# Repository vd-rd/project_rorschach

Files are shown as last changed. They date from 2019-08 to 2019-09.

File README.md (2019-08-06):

## E-Ink Driving board

E-Ink screens have a lot of advantages compared to traditional TFT displays. They can hold the image painted without power applied, making them usefull for low power/embedded applications. Moreover, from eastern suppliers they can be aquired for modest prices (comparing with the price of a LCD with the same diagonal). However, documentation is scarce and they require additional control and power requirements. This project addresses this shortcomings providing an open, modular hardware platform for driving various e-ink displays from a simple uController.

More information about suported screens and features can be found [here](docs/MATRIX.md).

### Technical features:
  - provides voltages for displays upto 10inch (VEE, VNEG, VCOM, VCC, VPOS, VDDH)
  - generates control signals for syncing data to screen
  - reads waveform from screen eeprom
  - leverages displaying data on the screen using the embedded FPGA

### Resources used:
  - http://essentialscrap.com/eink/
  - http://spritesmods.com/?art=einkdisplay
  - https://hackaday.io/project/21168-fpga-eink-controller
  - https://wenku.baidu.com/view/00bbfb6727d3240c8447efd5.html?pn=NaN
  - https://github.com/plasticlogic/libplhw/
  - http://www.gocompanion.co/index.php
  - https://github.com/dqydj/PaperBack_EPaper_Display
  - https://hackaday.io/project/11537-nekocal-an-e-ink-calendar

Essential parts:
  - iCE40HX1
  - TPS65185

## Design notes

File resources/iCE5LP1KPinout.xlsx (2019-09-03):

# Pin Out For iCE40 Ultra 1K
# Revision 0.6, Fixed Differential Pair Column
# Updated May 1, 2015
FNC | Pin Type | BANK | Differential Pair | WLCS36 | CM36A | SG48
IOB_0a | DPIO | 2 | TRUE_of_IOB_1b | - | D6 | 46
IOB_1b | DPIO | 2 | TRUE_of_IOB_0a | - | D1 | -
IOB_2a | DPIO | 2 | TRUE_of_IOB_3b | F6 | C1 | 47
IOB_3b_G6 | DPIO / GBIN | 2 | COMP_of_IOB_2a | E6 | D2 | 44
IOB_4a | DPIO | 2 | TRUE_of_IOB_5b | D6 | F1 | 48
IOB_5b | DPIO | 2 | COMP_of_IOB_4a | D5 | E1 | 45
IOB_6a | DPIO | 2 | TRUE_of_IOB_7b | F5 | F3 | 2
IOB_7b | DPIO | 2 | COMP_of_IOB_6a | E5 | E2 | -
IOB_8a | PIO | 2 | TRUE_of_IOB_9b | - | F2 | 4
IOB_9b | PIO | 2 | COMP_of_IOB_8a | - | - | 3
IOB_10a | DPIO | 1 | TRUE_of_IOB_11b | B4 | - | -
IOB_11b_G5 | PIO / GBIN | 1 | COMP_of_IOB_10a | F4 | - | -
creset_b | CONFIG | 1 |  | D3 | F4 | 8
IOB_13b | PIO | 1 |  | - | - | 6
CDONE | CONFIG | 1 |  | - | - | 7
IOB_16a | PIO | 1 |  | F3 | - | 9
IOB_18a | PIO | 1 |  | - | - | 10
IOB_20a | PIO | 1 |  | E3 | - | 11
IOB_22a | PIO | 1 | TRUE_of_IOB_23b | - | - | 12
IOB_23b | PIO | 1 | COMP_of_IOB_22a | - | - | 21
IOB_24a | PIO | 1 |  | - | - | 13
IOB_25b_G3 | PIO / GBIN | 1 |  | C2 | - | 20
IOB_26a | DPIO | 1 | TRUE_of_IOB_27b | B1 | - | -
IOB_27b | DPIO | 1 | COMP_of_IOB_26a | D2 | - | -
IOB_29b | PIO | 1 |  | E2 | - | 19
IOB_30a | DPIO | 1 | TRUE_of_IOB_31b | C1 | - | -
IOB_31b | DPIO | 1 | COMP_of_IOB_30a | B2 | - | 18
IOB_32a_SPI_SO | PIO / CONFIG_SPI | 1 |  | F2 | F6 | 14
IOB_33b_SPI_SI | PIO / CONFIG_SPI | 1 |  | D1 | E5 | 17
IOB_34a_SPI_SCK | PIO / CONFIG_SPI | 1 |  | E1 | E6 | 15
IOB_35b_SPI_CSN | PIO / CONFIG_SPI | 1 |  | F1 | F5 | 16
IOT_36b | PIO | 0 | COMP_of_IOT_37a | - | B2 | 25
IOT_37a | PIO | 0 | TRUE_of_IOT_36b | - | C2 | 23
IOT_38b | PIO | 0 | COMP_of_IOT_39a | - | A3 | 27
IOT_39a | PIO | 0 | TRUE_of_IOT_38b | - | - | 26
IOT_41a | PIO | 0 |  | - | - | 28
IOT_42b | PIO | 0 | COMP_of_IOT_43a | - | A4 | 31
IOT_43a | PIO | 0 | TRUE_of_IOT_42b | - | - | 32
IOT_44b | PIO | 0 | COMP_of_IOT_45a | - | - | 34
IOT_45a_G1 | PIO / GBIN | 0 | TRUE_of_IOT_44b | - | C6 | 37
IOT_46b_G0 | PIO / GBIN | 0 |  | B5 | B6 | 35
IOT_48b | PIO | 0 | COMP_of_IOT_49a | - | A5 | 36
IOT_49a | PIO | 0 | TRUE_of_IOT_48b | - | - | 43
IOT_50b | PIO | 0 | COMP_of_IOT_51a | - | B5 | 38
IOT_51a | PIO | 0 | TRUE_of_IOT_50b | - | - | 42
RGB2 | LED | 0 |  | A6 | A1 | 39
RGB1 | LED | 0 |  | B6 | B1 | 40
RGB0 | LED | 0 |  | C6 | A2 | 41
GND | GND | GND |  | A3 | C3 | -
GND | GND | GND |  | C5 | C4 | -
VCC | VCC | VCC |  | A5 | D3 | 5
VCC | VCC | VCC |  | - | - | 30
VCCIO_0 | VCCIO | 0 |  | A4 | B3 | 33
VCCIO_2 | VCCIO | 2 |  | C4 | E3 | 1
SPI_Vccio1 | VCCIO | 1 |  | C3 | E4 | 22
VCCPLL | VCCPLL | VCCPLL |  | B3 | D4 | 29
VPP_2V5 | VPP | VPP |  | D4 | B4 | 24
IOB_9b_CDONE | PIO / CONFIG | 2 |  | - | D5 | -
IOB_12A_G4_CDONE | PIO / GBIN / CONFIG | 1 |  | E4 | - | -
IRLED | IRLED | 0 |  | A2 | A6 | -
GND_led | GND_LED | GND_LED |  | A1 | C5 | -

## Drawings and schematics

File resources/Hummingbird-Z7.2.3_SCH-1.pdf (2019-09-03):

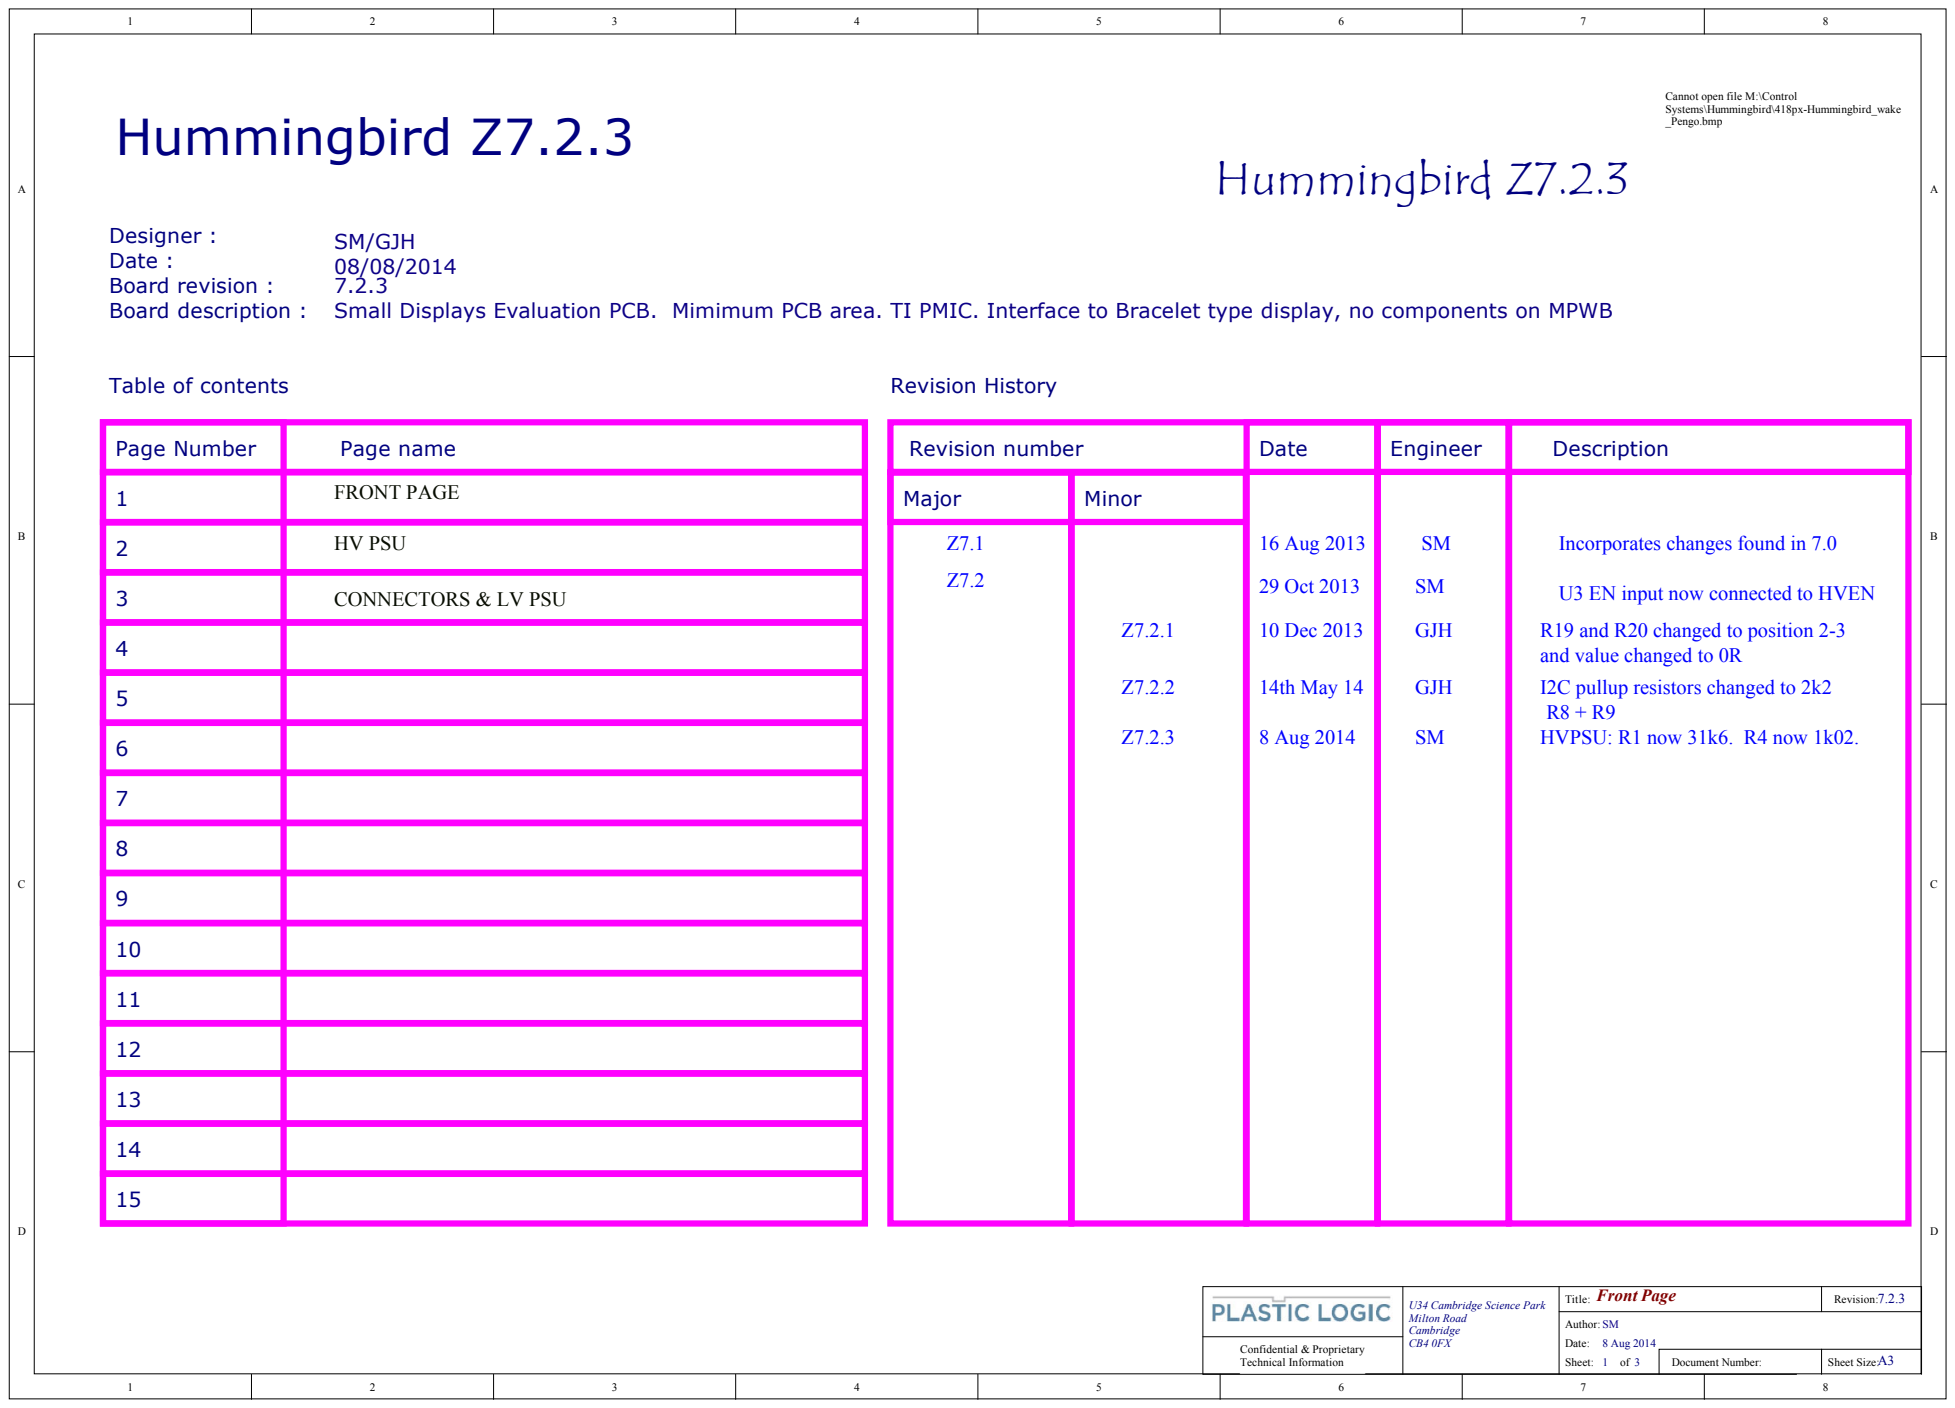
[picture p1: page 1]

Cannot open file M:\Control
Systems\Hummingbird\418px-Hummingbird_wake
_Pengo.bmp

SM/GJH
Small Displays Evaluation PCB. Mimimum PCB area. TI PMIC. Interface to Bracelet type display, no components on MPWB

2 | HV PSU

3 | CONNECTORS & LV PSU

and value changed to 0R

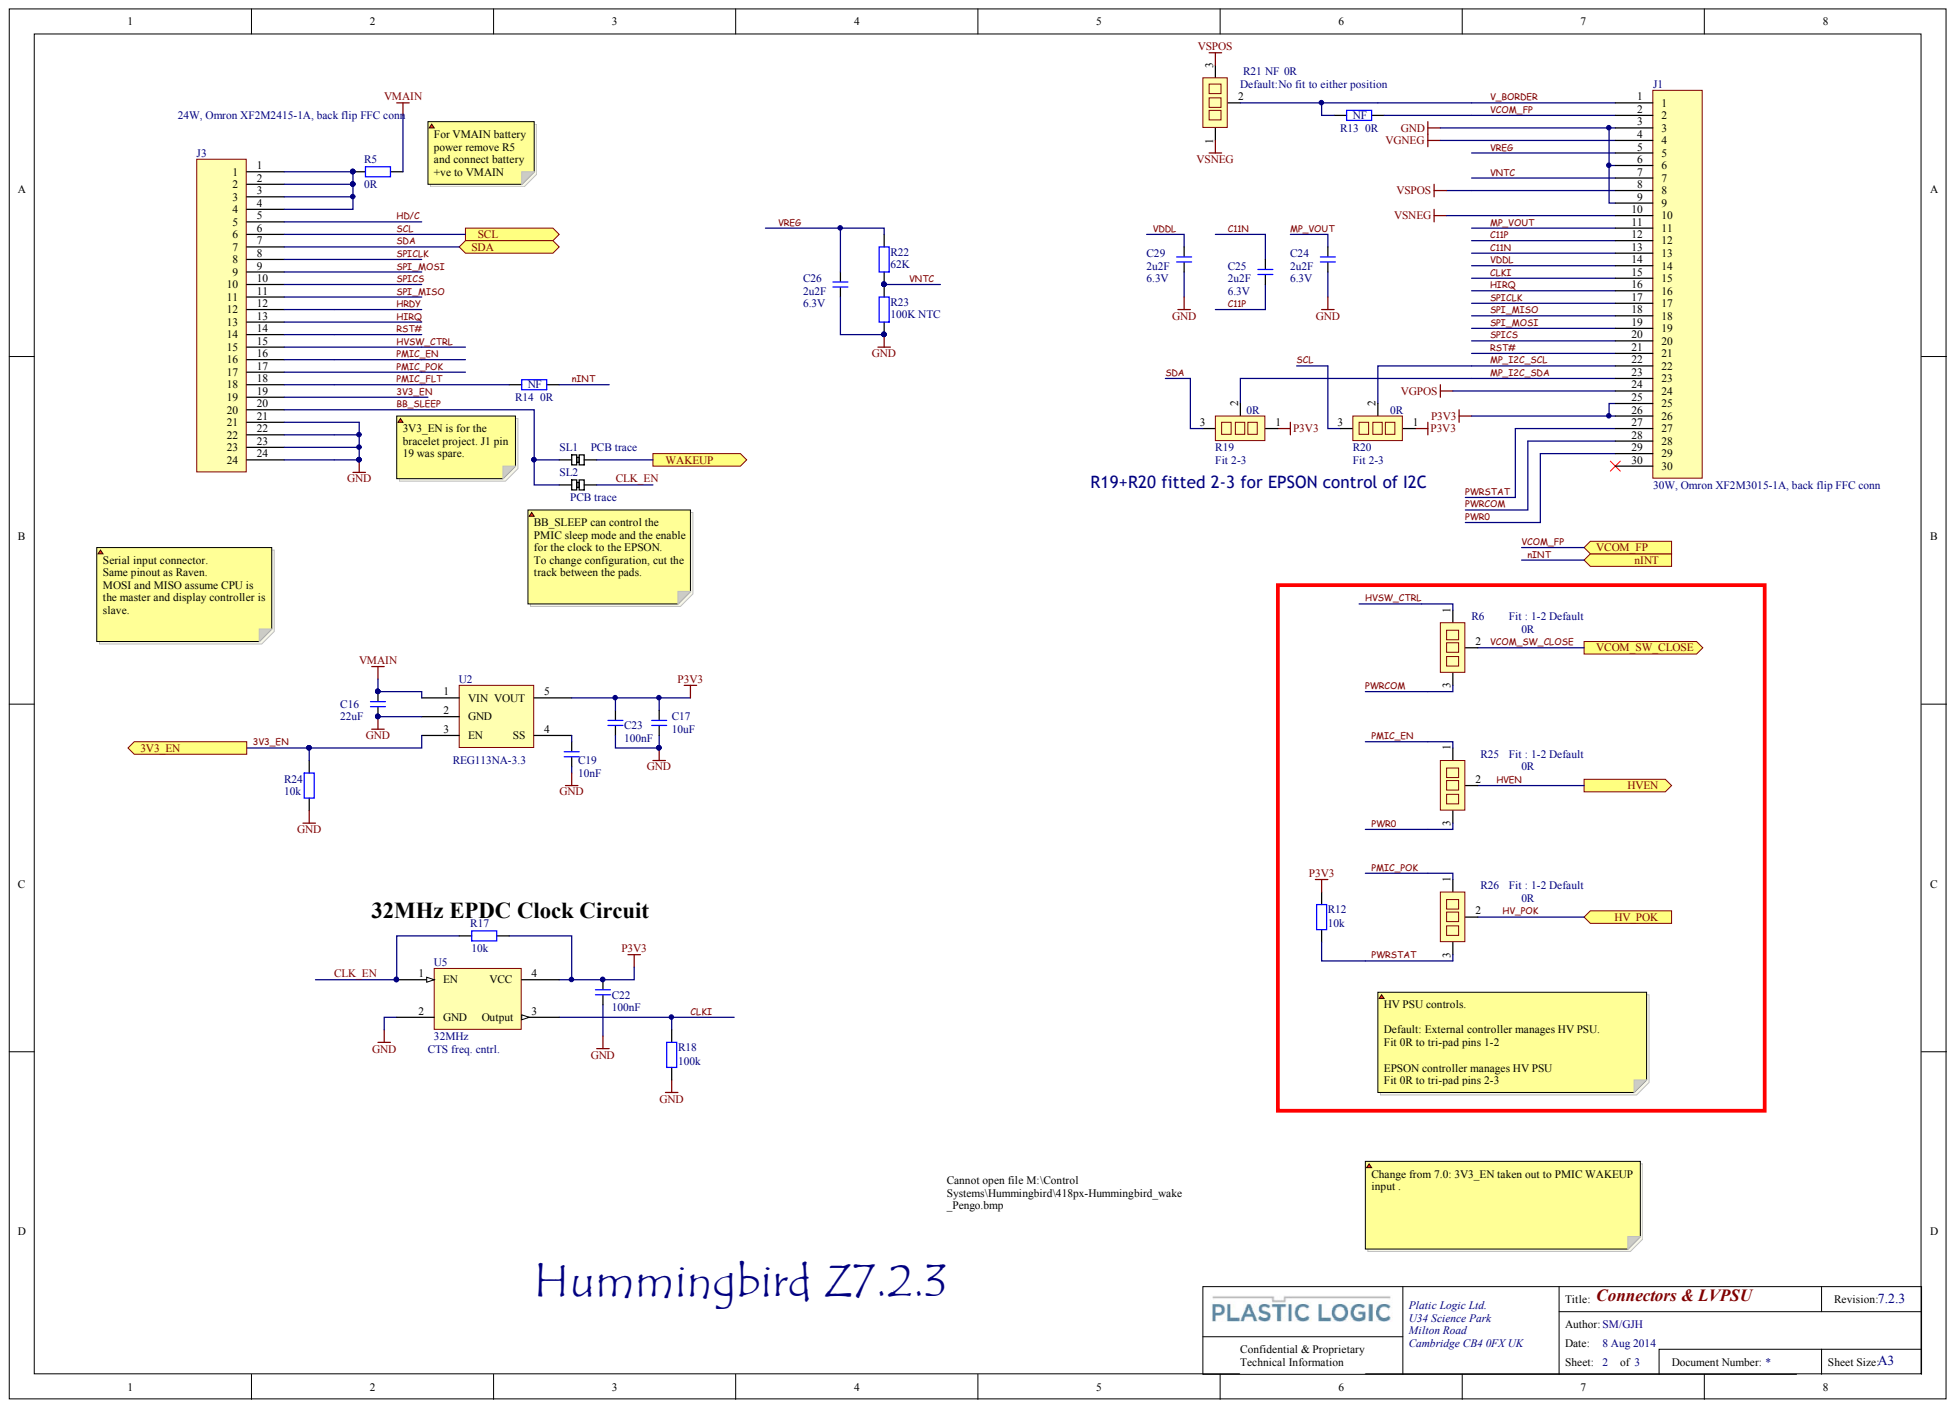
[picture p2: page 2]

Default:No fit to either position

24W, Omron XF2M2415-1A, back flip FFC conn

VREG | 5 5

R19+R20 fitted 2-3 for EPSON control of I2C

30W, Omron XF2M3015-1A, back flip FFC conn

BB_SLEEP can control the
PMIC sleep mode and the enable
for the clock to the EPSON.
To change configuration, cut the
track between the pads.

Serial input connector.
Same pinout as Raven.
MOSI and MISO assume CPU is
the master and display controller is
slave.

Default: External controller manages HV PSU.
Fit 0R to tri-pad pins 1-2

EPSON controller manages HV PSU
Fit 0R to tri-pad pins 2-3

Cannot open file M:\Control
Systems\Hummingbird\418px-Hummingbird_wake
_Pengo.bmp

Change from 7.0: 3V3_EN taken out to PMIC WAKEUP
input .

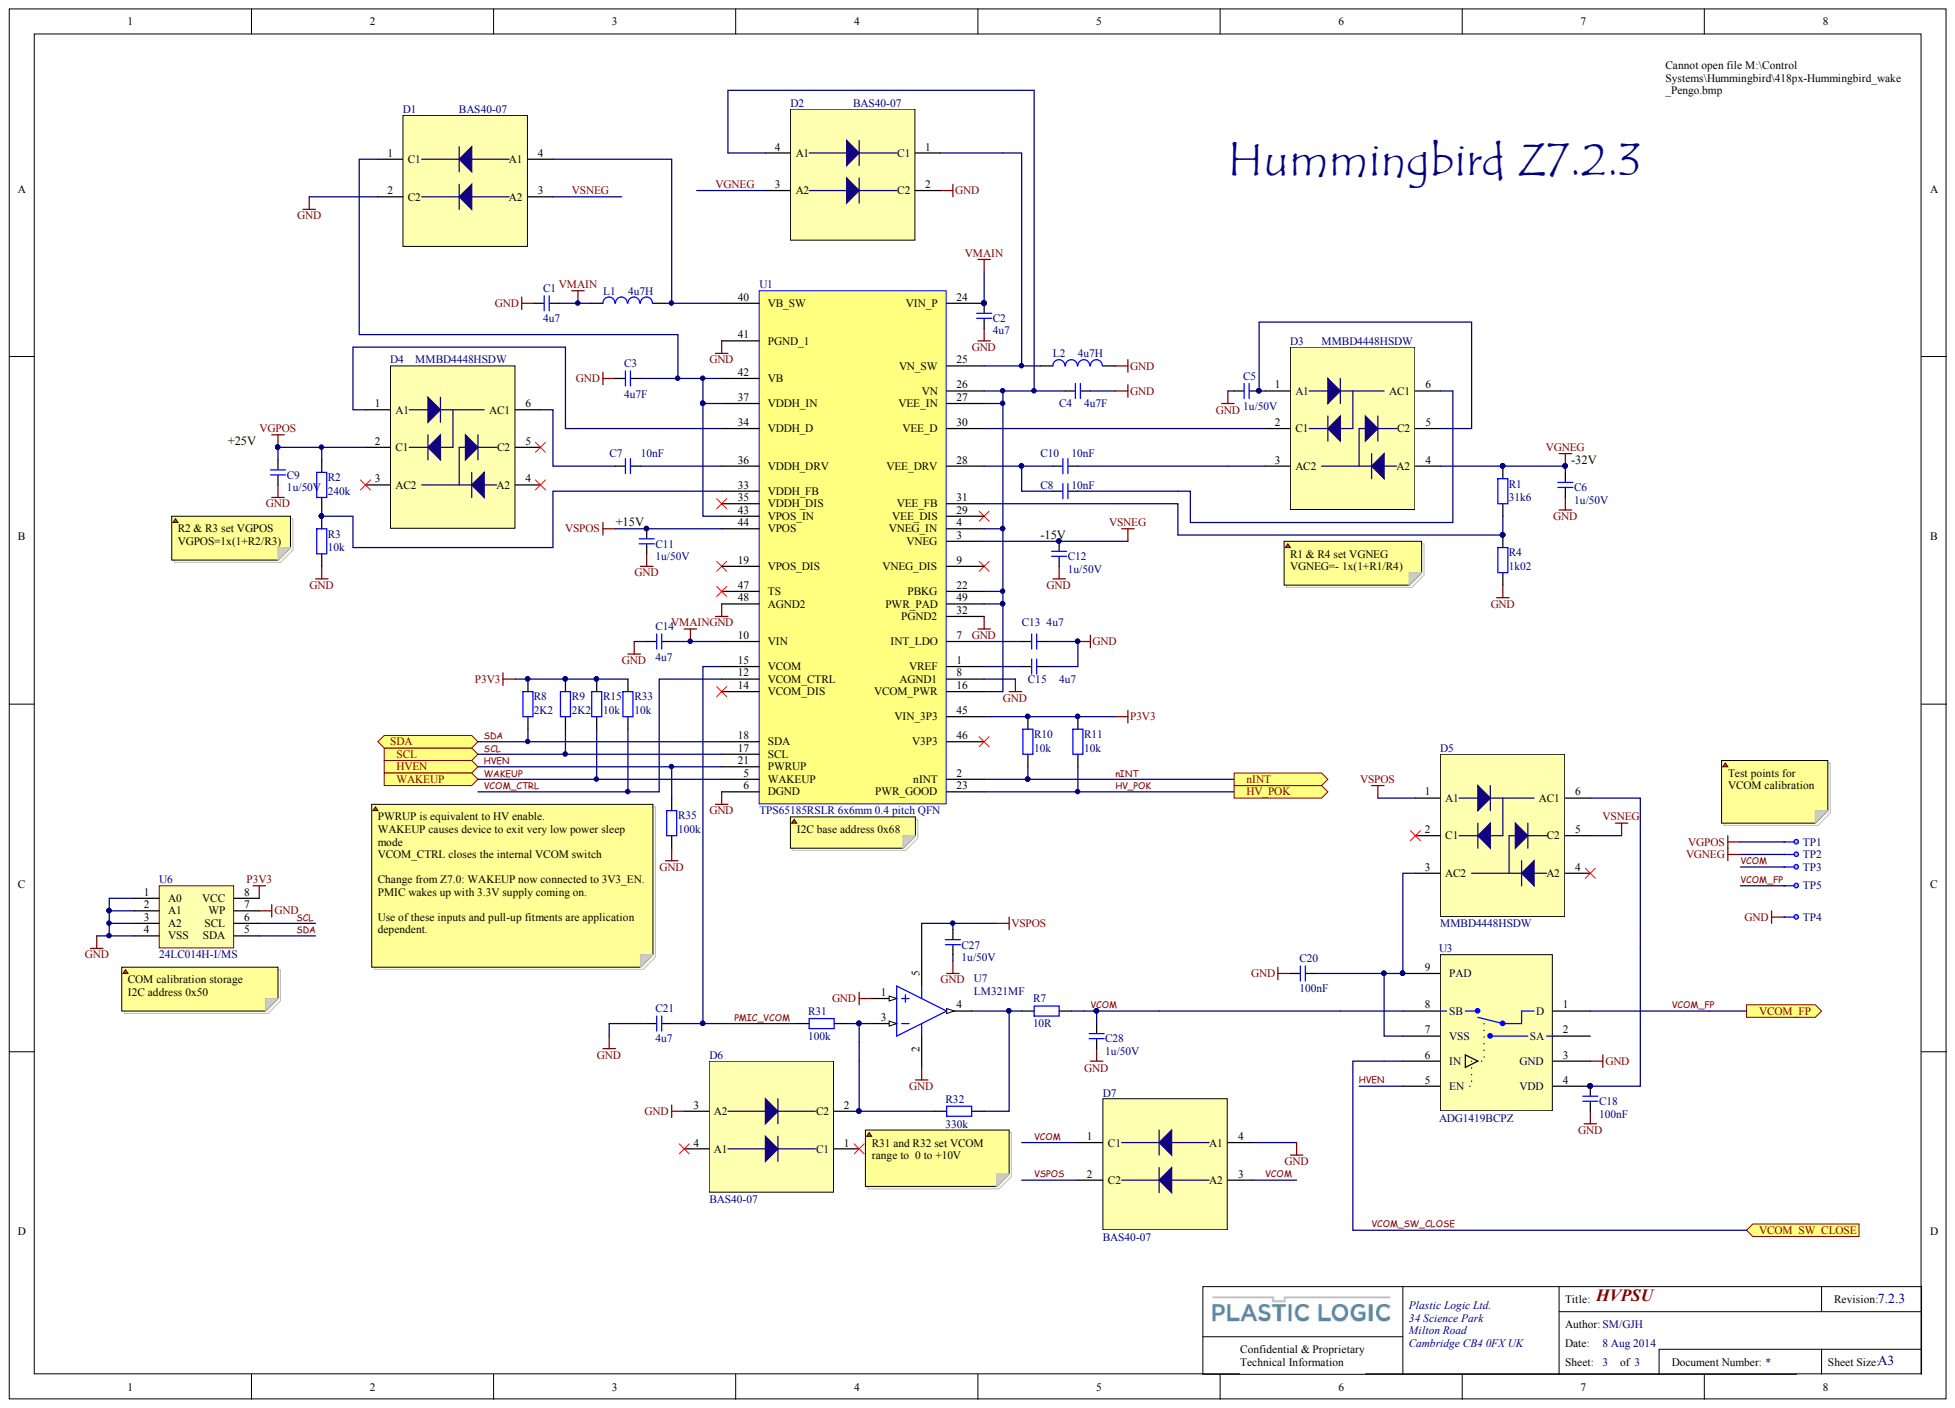
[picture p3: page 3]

Cannot open file M:\Control
Systems\Hummingbird\418px-Hummingbird_wake
_Pengo.bmp

VSNEG

VMAIN

VCOM_DIS 14

SCL | | | SCL 17
HVEN | | | PWRUP 21

VCOM_CTRL | DGND 6 | | HV_POK

WAKEUP 5

PWRUP is equivalent to HV enable.
WAKEUP causes device to exit very low power sleep
mode
VCOM_CTRL closes the internal VCOM switch

C1 2 | VSNEG

Change from Z7.0: WAKEUP now connected to 3V3_EN.
PMIC wakes up with 3.3V supply coming on.

Use of these inputs and pull-up fitments are application
dependent.

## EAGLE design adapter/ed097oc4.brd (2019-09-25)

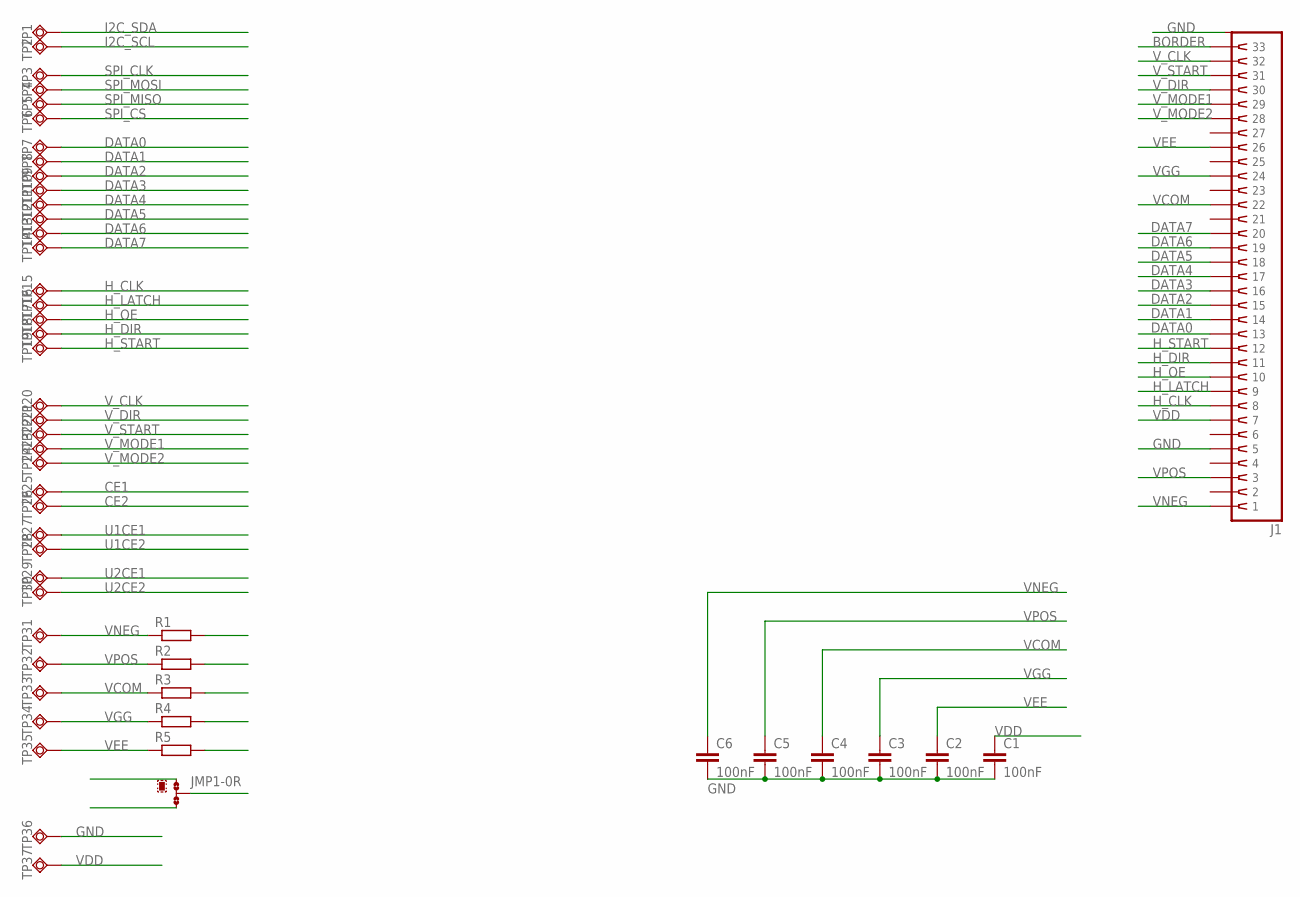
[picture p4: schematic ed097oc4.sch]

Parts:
C1, C2, C3, C4, C5, C6: 100nF; C0805
J1: SFV33R; SFV33R-1STE1LF
JMP1: 0R-JUMPA; A0R-JMP
R1, R2, R3, R4, R5: R-EU_R0805; R0805
TP1, TP2, TP3, TP4, TP5, TP6, TP7, TP8, TP9, TP10, TP11, TP12, TP13, TP14, TP15, TP16, TP17, TP18, TP19, TP20, TP21, TP22, TP23, TP24, TP25, TP26, TP27, TP28, TP29, TP30, TP31, TP32, TP33, TP34, TP35, TP36, TP37: TESTPAD0.6; VIA0.6

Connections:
BORDER: J1.33
CE1: TP25.P$1
CE2: TP26.P$1
DATA0: J1.13, TP7.P$1
DATA1: J1.14, TP8.P$1
DATA2: J1.15, TP9.P$1
DATA3: J1.16, TP10.P$1
DATA4: J1.17, TP11.P$1
DATA5: J1.18, TP12.P$1
DATA6: J1.19, TP13.P$1
DATA7: J1.20, TP14.P$1
GND: C1.2, C2.2, C3.2, C4.2, C5.2, C6.2, J1.5, J1.SHLD1 (SHLD), J1.SHLD2 (SHLD), TP36.P$1
H_CLK: J1.8, TP15.P$1
H_DIR: J1.11, TP18.P$1
H_LATCH: J1.9, TP16.P$1
H_OE: J1.10, TP17.P$1
H_START: J1.12, TP19.P$1
I2C_SCL: TP2.P$1
I2C_SDA: TP1.P$1
SPI_CLK: TP3.P$1
SPI_CS: TP6.P$1
SPI_MISO: TP5.P$1
SPI_MOSI: TP4.P$1
U1CE1: TP27.P$1
U1CE2: TP28.P$1
U2CE1: TP29.P$1
U2CE2: TP30.P$1
VCOM: C4.1, J1.22, R3.1, TP33.P$1
VDD: C1.1, J1.7, TP37.P$1
VEE: C2.1, J1.26, R5.1, TP35.P$1
VGG: C3.1, J1.24, R4.1, TP34.P$1
VNEG: C6.1, J1.1, R1.1, TP31.P$1
VPOS: C5.1, J1.3, R2.1, TP32.P$1
V_CLK: J1.32, TP20.P$1
V_DIR: J1.30, TP21.P$1
V_MODE1: J1.29, TP23.P$1
V_MODE2: J1.28, TP24.P$1
V_START: J1.31, TP22.P$1

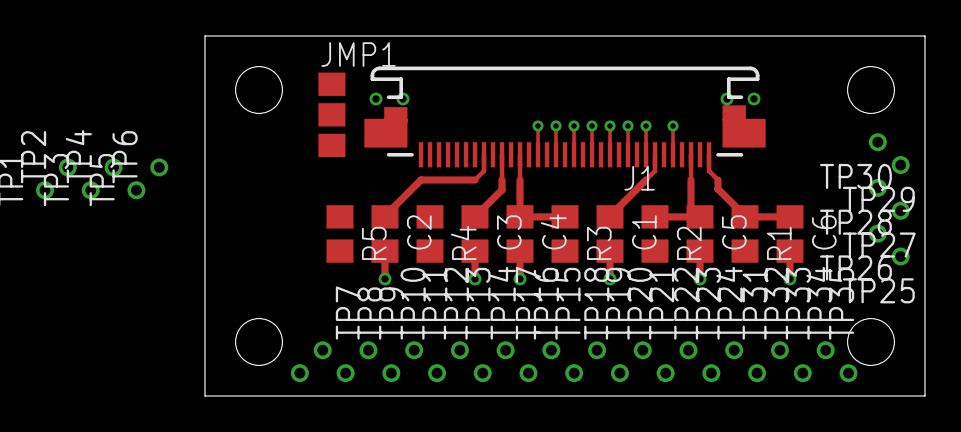
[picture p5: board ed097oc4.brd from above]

Board: 2 copper layers, 40.0 x 20.0 mm, 50 parts (0 on the bottom side), 25 nets.

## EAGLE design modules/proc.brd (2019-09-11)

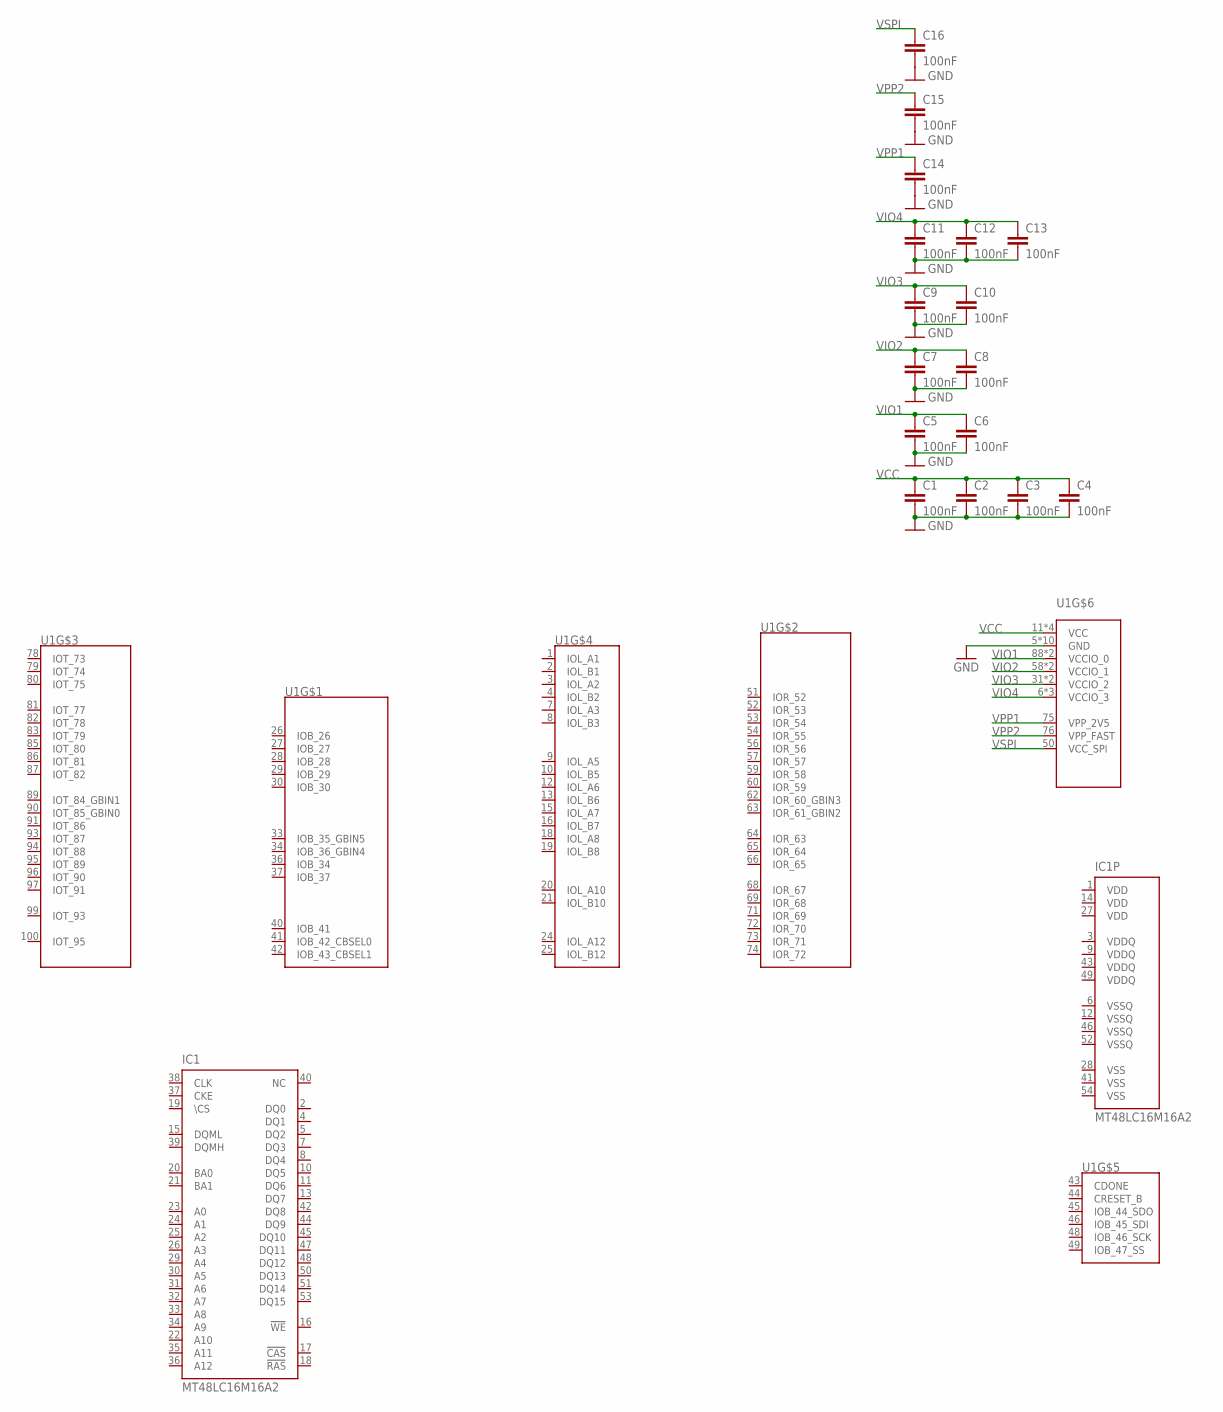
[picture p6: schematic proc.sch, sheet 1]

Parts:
C1, C2, C3, C4, C5, C6, C7, C8, C9, C10, C11, C12, C13, C14, C15, C16: 100nF; C0603
IC1: MT48LC16M16A2; TSOP54-400
U1: ICE40-HX1K-100VQ; QFP50P1600X1600X120-100

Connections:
GND: C1.2, C2.2, C3.2, C4.2, C5.2, C6.2, C7.2, C8.2, C9.2, C10.2, C11.2, C12.2, C13.2, C14.2, C15.2, C16.2, U1.5 (GND), U1.17 (GND), U1.23 (GND), U1.32 (GND), U1.39 (GND), U1.47 (GND), U1.55 (GND), U1.70 (GND), U1.84 (GND), U1.98 (GND)
VCC: C1.1, C2.1, C3.1, C4.1, U1.11 (VCC), U1.35 (VCC), U1.61 (VCC), U1.77 (VCC)
VDD: IC1.1 (VDD), IC1.14 (VDD), IC1.27 (VDD)
VDDQ: IC1.3 (VDDQ), IC1.9 (VDDQ), IC1.43 (VDDQ), IC1.49 (VDDQ)
VIO1: C5.1, C6.1, U1.88 (VCCIO_0), U1.92 (VCCIO_0)
VIO2: C7.1, C8.1, U1.58 (VCCIO_1), U1.67 (VCCIO_1)
VIO3: C9.1, C10.1, U1.31 (VCCIO_2), U1.38 (VCCIO_2)
VIO4: C11.1, C12.1, C13.1, U1.6 (VCCIO_3), U1.14 (VCCIO_3), U1.22 (VCCIO_3)
VPP1: C14.1, U1.75 (VPP_2V5)
VPP2: C15.1, U1.76 (VPP_FAST)
VSPI: C16.1, U1.50 (VCC_SPI)
VSS: IC1.28 (VSS), IC1.41 (VSS), IC1.54 (VSS)
VSSQ: IC1.6 (VSSQ), IC1.12 (VSSQ), IC1.46 (VSSQ), IC1.52 (VSSQ)

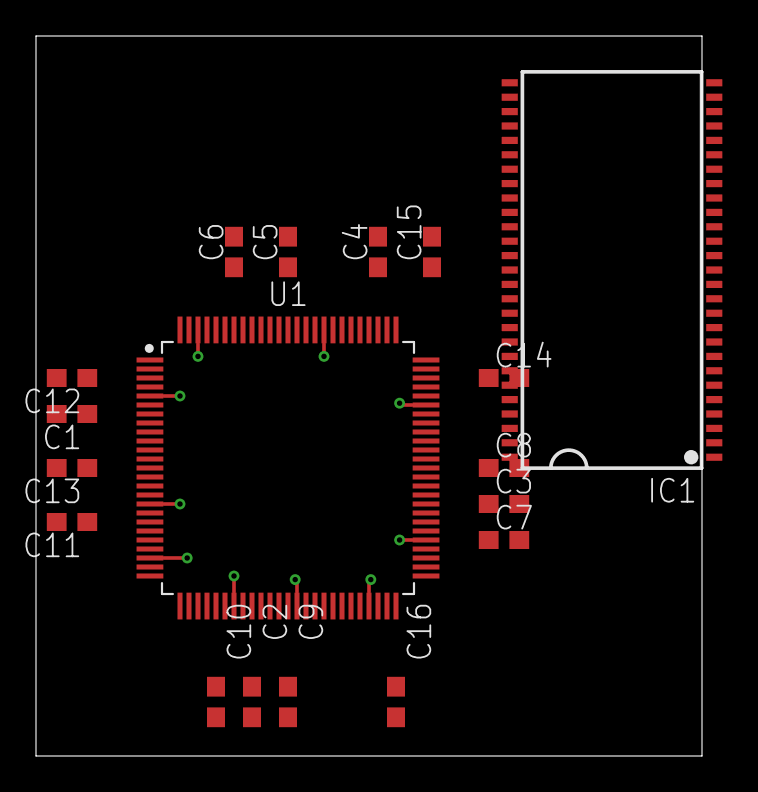
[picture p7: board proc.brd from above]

Board: 2 copper layers, 37.0 x 40.0 mm, 18 parts (0 on the bottom side), 13 nets.

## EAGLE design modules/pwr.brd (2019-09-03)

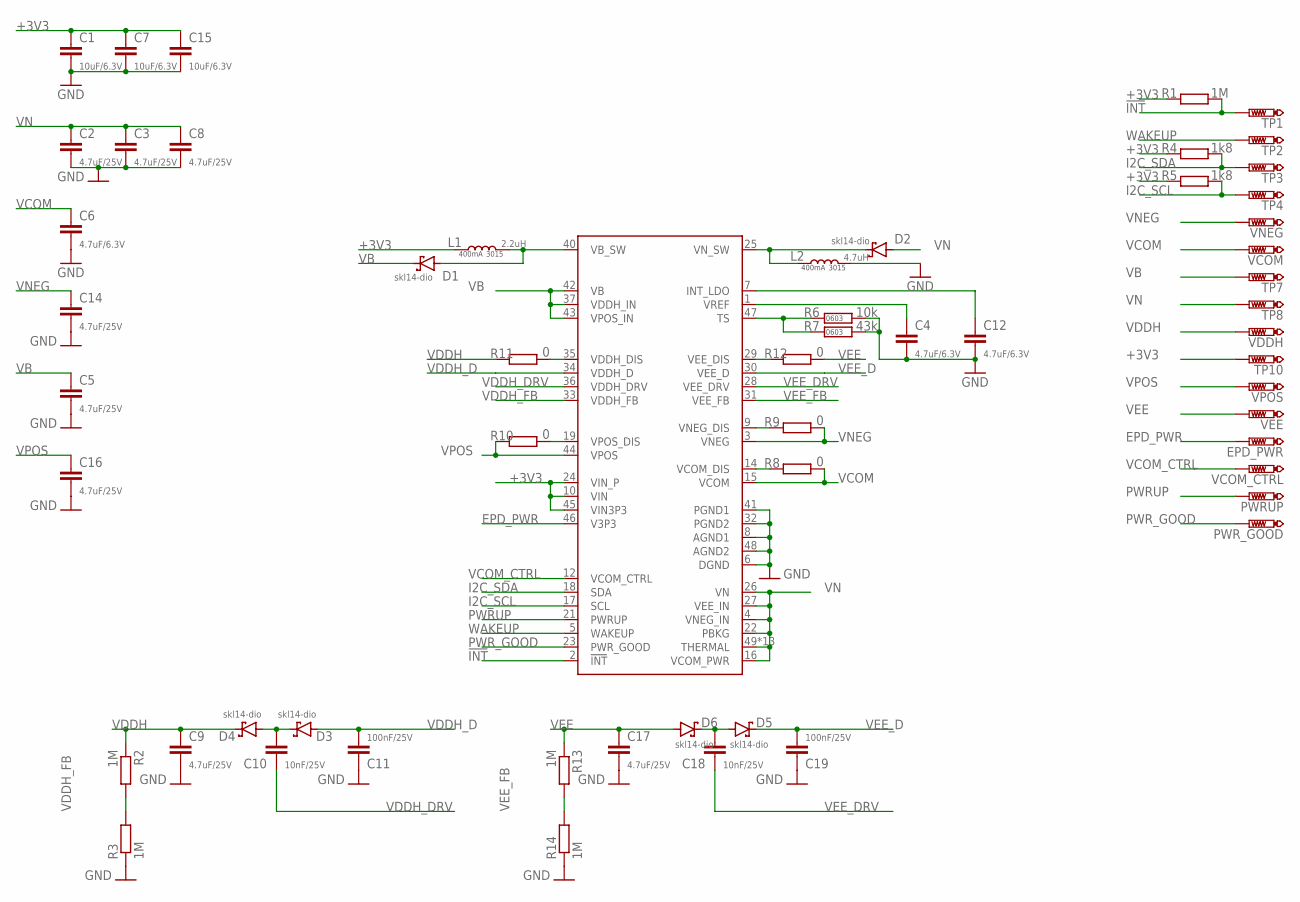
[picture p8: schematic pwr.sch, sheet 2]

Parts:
C1, C7, C15: 10uF/6.3V; C0805
C2, C3, C5, C8, C9, C14, C16, C17: 4.7uF/25V; C0805
C4, C6, C12: 4.7uF/6.3V; C0603
C10, C18: 10nF/25V; C0402
C11, C19: 100nF/25V; C0603
D1, D2, D3, D4, D5, D6: skl14-dio; SODFL3718X130
EPD_PWR: PTR1B1,27; B1,27
L1: 2.2uH; L3230M
L2: 4.7uH; L3230M
PWRUP: PTR1B1,27; B1,27
PWR_GOOD: PTR1B1,27; B1,27
R1, R2, R3, R13, R14: 1M; R0603
R4, R5: 1k8; R0603
R6: 10k; R0603
R7: 43k; R0603
R8, R9, R10, R11, R12: 0; R0402
TP1, TP2, TP3, TP4, TP7, TP8, TP10: PTR1B1,27; B1,27
U1: TPS65185; QFN50P700X700X100-49T410
VCOM: PTR1B1,27; B1,27
VCOM_CTRL: PTR1B1,27; B1,27
VDDH: PTR1B1,27; B1,27
VEE: PTR1B1,27; B1,27
VNEG: PTR1B1,27; B1,27
VPOS: PTR1B1,27; B1,27

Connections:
!INT: R1.2, TP1.TP, U1.2 (!INT)
+3V3: C1.1, C7.1, C15.1, L1.1, R1.1, R4.1, R5.1, TP10.TP, U1.10 (VIN), U1.24 (VIN_P), U1.45 (VIN3P3)
EPD_PWR: EPD_PWR.TP, U1.46 (V3P3)
GND: C1.2, C2.2, C3.2, C4.2, C5.2, C6.2, C7.2, C8.2, C9.2, C11.2, C12.2, C14.2, C15.2, C16.2, C17.2, C19.2, L2.2, R3.1, R6.2, R7.2, R14.1, U1.6 (DGND), U1.8 (AGND1), U1.32 (PGND2), U1.41 (PGND1), U1.48 (AGND2)
I2C_SCL: R5.2, TP4.TP, U1.17 (SCL)
I2C_SDA: R4.2, TP3.TP, U1.18 (SDA)
unnamed: C12.1, U1.7 (INT_LDO)
unnamed: D1.A, L1.2, U1.40 (VB_SW)
unnamed: D2.C, L2.1, U1.25 (VN_SW)
unnamed: C4.1, U1.1 (VREF)
unnamed: R6.1, R7.1, U1.47 (TS)
unnamed: C10.1, D3.C, D4.A
unnamed: R8.1, U1.14 (VCOM_DIS)
unnamed: C18.1, D5.A, D6.C
unnamed: R9.1, U1.9 (VNEG_DIS)
unnamed: R10.2, U1.19 (VPOS_DIS)
unnamed: R12.1, U1.29 (VEE_DIS)
unnamed: R11.2, U1.35 (VDDH_DIS)
PWRUP: PWRUP.TP, U1.21 (PWRUP)
PWR_GOOD: PWR_GOOD.TP, U1.23 (PWR_GOOD)
VB: C5.1, D1.C, TP7.TP, U1.37 (VDDH_IN), U1.42 (VB), U1.43 (VPOS_IN)
VCOM: C6.1, R8.2, U1.15 (VCOM), VCOM.TP
VCOM_CTRL: U1.12 (VCOM_CTRL), VCOM_CTRL.TP
VDDH: C9.1, D4.C, R2.1, R11.1, VDDH.TP
VDDH_D: C11.1, D3.A, U1.34 (VDDH_D)
VDDH_DRV: C10.2, U1.36 (VDDH_DRV)
VDDH_FB: R2.2, R3.2, U1.33 (VDDH_FB)
VEE: C17.1, D6.A, R12.2, R13.1, VEE.TP
VEE_D: C19.1, D5.C, U1.30 (VEE_D)
VEE_DRV: C18.2, U1.28 (VEE_DRV)
VEE_FB: R13.2, R14.2, U1.31 (VEE_FB)
VN: C2.1, C3.1, C8.1, D2.A, TP8.TP, U1.4 (VNEG_IN), U1.16 (VCOM_PWR), U1.22 (PBKG), U1.26 (VN), U1.27 (VEE_IN), U1.49 (THERMAL), U1.P$1 (THERMAL), U1.P$2 (THERMAL), U1.P$3 (THERMAL), U1.P$4 (THERMAL), U1.P$5 (THERMAL), U1.P$6 (THERMAL), U1.P$7 (THERMAL), U1.P$8 (THERMAL), U1.P$9 (THERMAL), U1.P$10 (THERMAL), U1.P$11 (THERMAL), U1.P$12 (THERMAL)
VNEG: C14.1, R9.2, U1.3 (VNEG), VNEG.TP
VPOS: C16.1, R10.1, U1.44 (VPOS), VPOS.TP
WAKEUP: TP2.TP, U1.5 (WAKEUP)

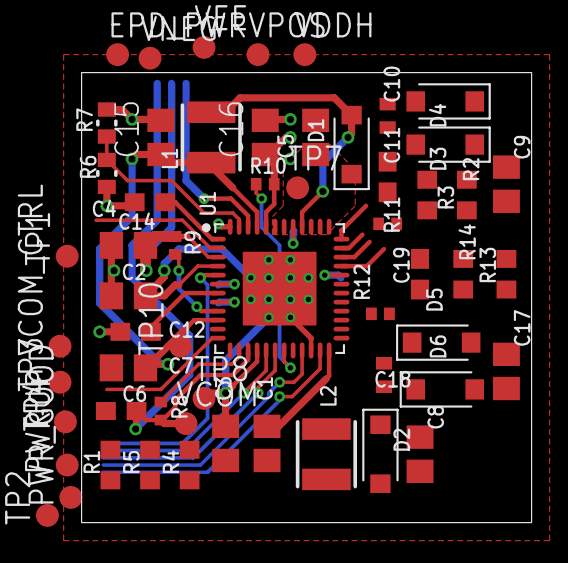
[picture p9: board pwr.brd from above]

Board: 2 copper layers, 25.0 x 25.0 mm, 57 parts (0 on the bottom side), 35 nets.

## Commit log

2017-07-05 Added possible connector for e-ink display
2019-02-06 board variants
    [rev1.GBL, rev1.GBO, rev1.GBP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]
2019-08-06 project: rebase and upgrade structure
    [rev1.brd, rev1.sch]
2019-09-03 project: added test modules
    [iCE5LP1KPinout.xlsx, iCE5LP4KPinout.xlsx, proc.brd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]
2019-09-11 board: small fixes
    [proc.brd, proc.sch]
2019-09-25 project: add boilerplate adapter board for screen
    [boilerplate.brd, boilerplate.sch]
2019-09-25 project: added ed097oc4 adapter
    [boilerplate.sch, ed097oc4.brd, ed097oc4.sch]
